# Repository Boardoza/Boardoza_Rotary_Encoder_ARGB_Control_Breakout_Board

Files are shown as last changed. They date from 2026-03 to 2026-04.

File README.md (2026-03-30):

# Boardoza Rotary Encoder EC1101S Breakout Board

The **Boardoza Rotary Encoder EC1101S Breakout Board** is a multifunctional input and visual feedback solution that combines a **mechanical rotary encoder with an integrated push button** and **addressable RGB LEDs (ARGB)** on a single compact PCB. This board converts rotational motion into digital signals while simultaneously enabling dynamic visual effects through programmable LEDs.

By integrating **14 cascaded ARGB LEDs** directly around the encoder, the board allows users to visually represent rotation, direction, speed, or system states. Each encoder movement can be interpreted by a microcontroller (such as Arduino, ESP32, or similar platforms) to control LED color, brightness, and animation patterns, making it ideal for interactive interfaces, control panels, and creative electronics projects.

## [Click here to purchase!](https://www.ozdisan.com/ureticiler/boardoza)

| Front Side | Back Side |
|:---:|:---:|
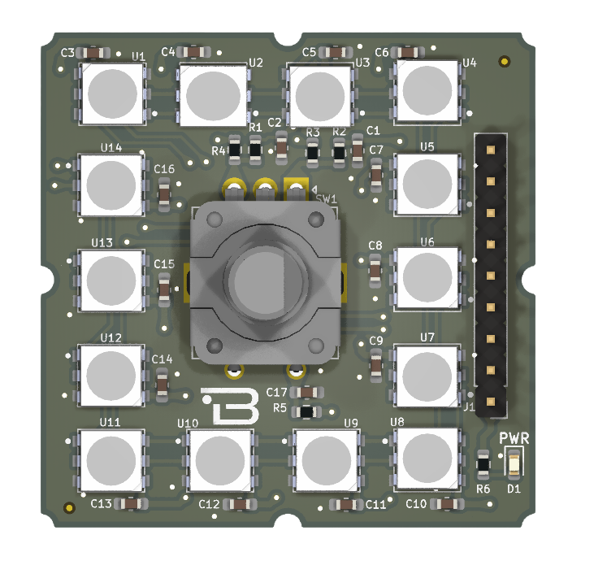
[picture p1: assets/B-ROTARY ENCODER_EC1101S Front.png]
ROTARY ENCODER EC1101S Front
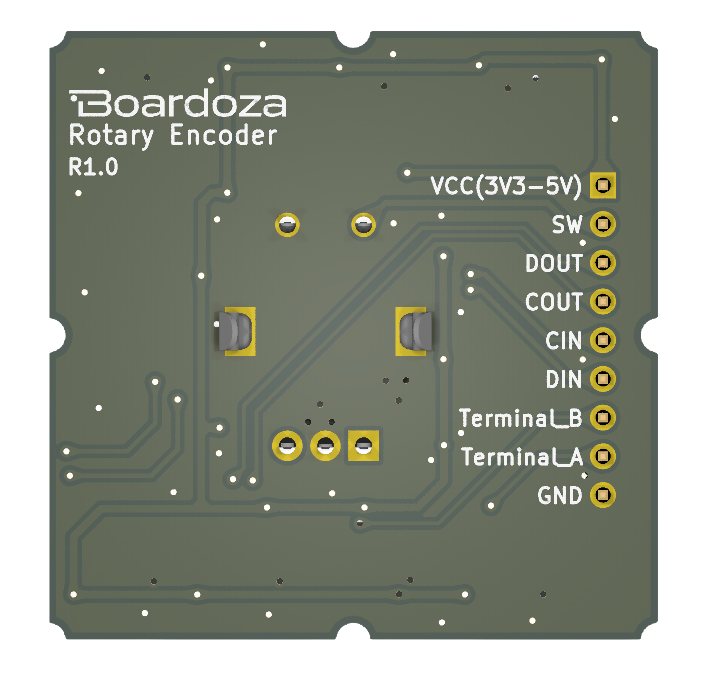
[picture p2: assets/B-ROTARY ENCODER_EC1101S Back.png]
ROTARY ENCODER EC1101S Back
|  |  |

---

## Key Features

- **Rotary Encoder with Push Button:** Mechanical rotary encoder with integrated momentary push button for menu navigation and user input.
- **Integrated Addressable RGB LEDs:** Features 14 cascaded ARGB LEDs for dynamic visual feedback and animation effects.
- **Quadrature Output Signals:** Provides A and B channel outputs for accurate direction and rotation detection.
- **Visual Motion Representation:** Encoder rotation can be visually expressed through programmable LED color, pattern, and brightness changes.
- **Wide Logic Compatibility:** Fully compatible with both 3.3 V and 5 V microcontroller systems.
- **Expandable LED Chain:** ARGB data and clock input/output pins allow cascading with additional LED boards.
- **20 Pulses per Revolution:** Provides 20 pulses per 360° rotation (per phase) for precise rotational detection.

---

## Technical Specifications  

**Model:** Rotary Encoder EC1101S  
**Manufacturer:** Boardoza  
**Encoder Type:** Mechanical rotary encoder with push button  
**LED Type:** Addressable RGB (ARGB)  
**Number of LEDs:** 14  
**LED Interface:** Serial Data (DIN/DOUT), Clock (CIN/COUT)  
**Signal Outputs:** Encoder A, Encoder B, Push Button (SW)  
**Input Voltage:** 3.3 V / 5 V  
**Logic Level:** 3.3 V / 5 V compatible  
**Operating Temperature:** -40 °C to +85 °C  
**Board Dimensions:** 40 mm × 40 mm  

---

## Board Pinout

### **( J1 ) Main Connector**

| Pin Number | Pin Name | Description |
|:---:|:---:|---|
| 1 | VCC (3V3–5V) | Power supply input |
| 2 | SW | Encoder push button output (Active Low) |
| 3 | DOUT | ARGB serial data output |
| 4 | COUT | ARGB clock output |
| 5 | CIN | ARGB clock input |
| 6 | DIN | ARGB serial data input |
| 7 | Terminal_B | Encoder B channel output |
| 8 | Terminal_A | Encoder A channel output |
| 9 | GND | Ground |

---

## Board Dimensions

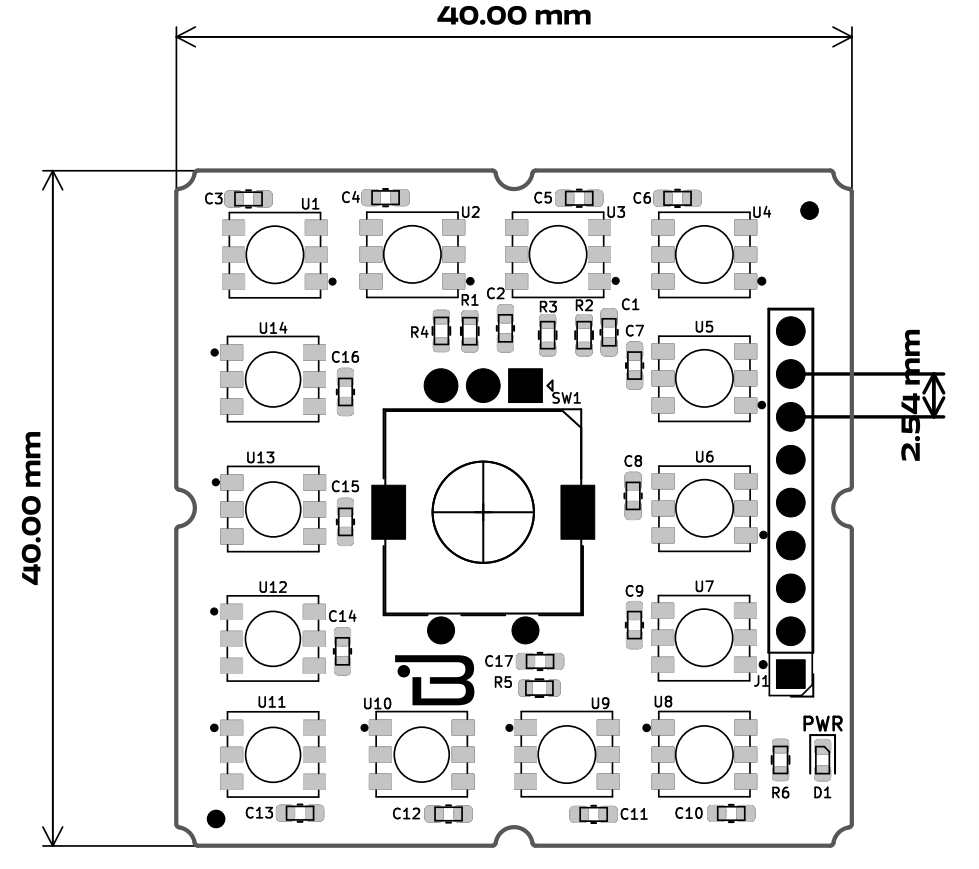
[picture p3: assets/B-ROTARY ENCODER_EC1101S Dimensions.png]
Board Dimensions


---

## Step Files

[Boardoza ROTARY ENCODER.step](./assets/B-ROTARY%20ENCODER_EC1101S%20Step.step)

---

## Datasheet

- [PLCC IC + RGB LEDs Datasheet.pdf](./assets/PLCC%20IC+RGB%20LEDs%20Datasheet.pdf)  
- [ROTARY ENCODER EC1101S Breakout Datasheet.pdf](./assets/B-ROTARY%20ENCODER_EC1101S%20Datasheet.pdf)

---

## Version History

- **V1.0.0** – Initial Release

---

## Support

- For questions or technical support, please contact **support@boardoza.com**

---

## **License**

This repository contains both hardware and software components:

### **Hardware Design**

[][cc-by-sa]

All hardware design files are licensed under [Creative Commons Attribution-ShareAlike 4.0 International License][cc-by-sa].

[cc-by-sa]: http://creativecommons.org/licenses/by-sa/4.0/
[cc-by-sa-shield]: https://img.shields.io/badge/License-CC%20BY--SA%204.0-lightgrey.svg

### **Software/Firmware**

[][bsd]

All software and firmware are licensed under [BSD 3-Clause License][bsd].

[bsd]: https://opensource.org/licenses/BSD-3-Clause
[bsd-shield]: https://img.shields.io/badge/License-BSD%203--Clause-blue.svg

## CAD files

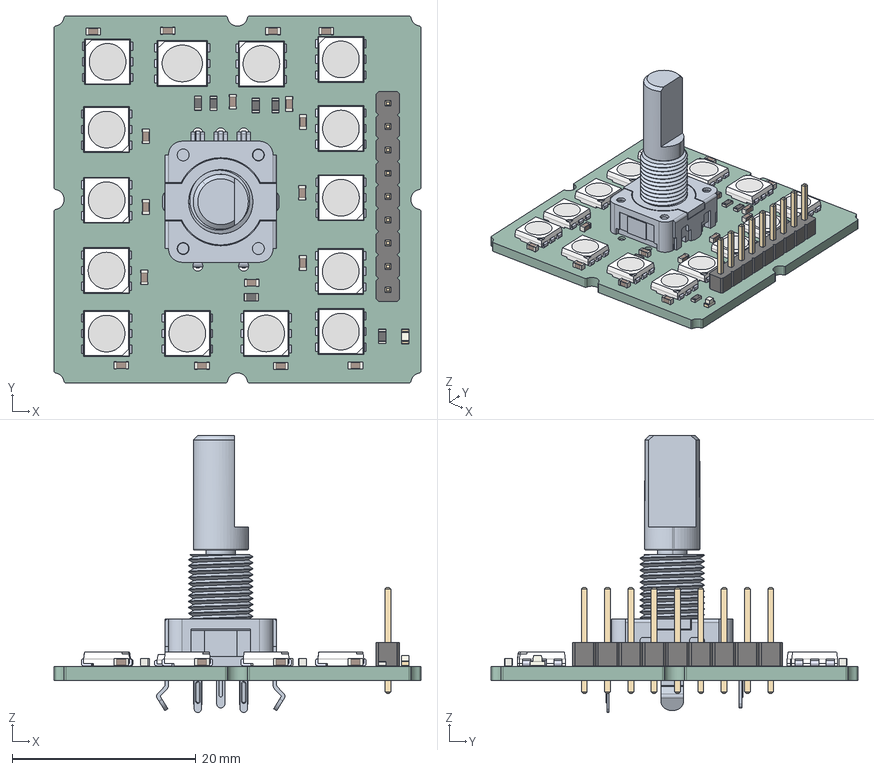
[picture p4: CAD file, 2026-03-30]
assets/B-ROTARY ENCODER_EC1101S Step.step
40.0 x 40.0 x 30.2 mm
C_0603_1608Metric x 17
IN-P55TATRGB--3DModel-STEP-56544 x 14
R_0603_1608Metric x 6
pec11r-4220f-n0012
PinHeader_1x09_P2.54mm_Vertical
LED_0603_1608Metric
B-ROTARY_ENCODER-BRK-01MBR-R01_PCB

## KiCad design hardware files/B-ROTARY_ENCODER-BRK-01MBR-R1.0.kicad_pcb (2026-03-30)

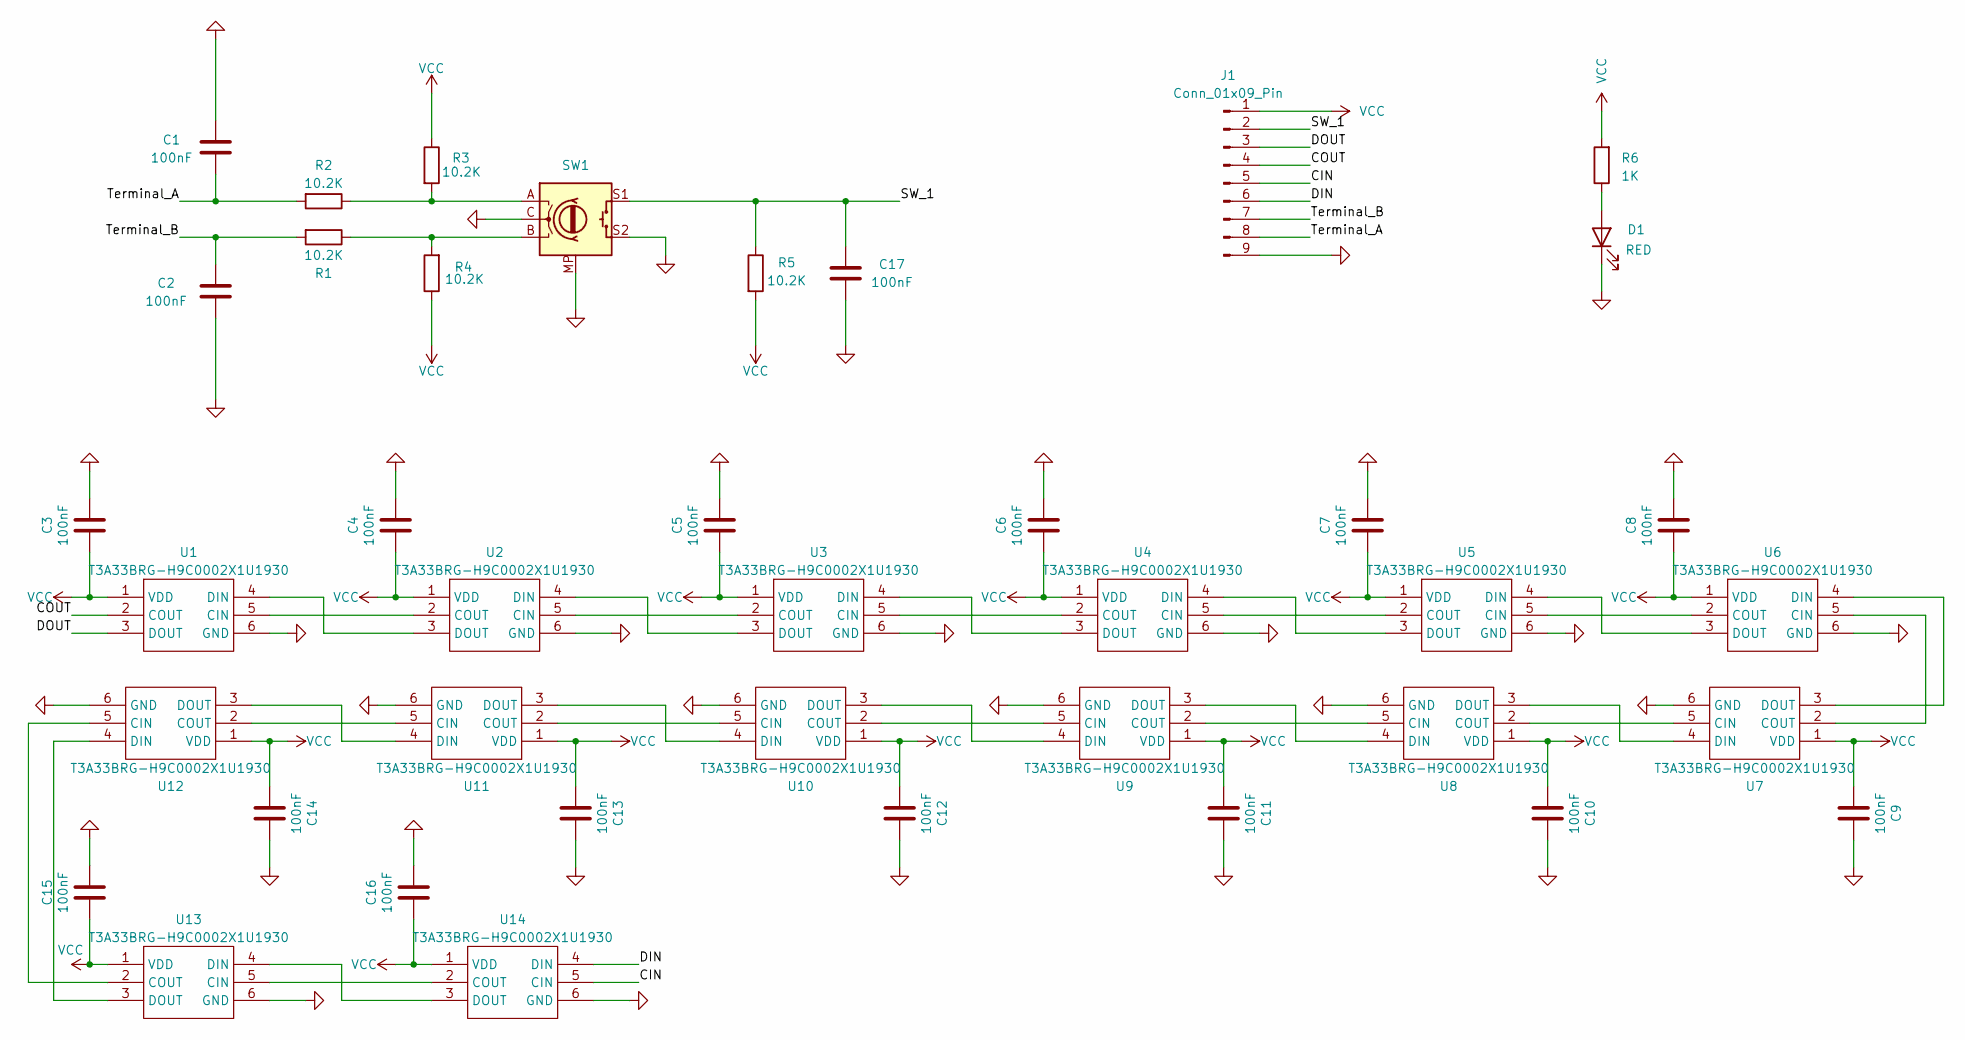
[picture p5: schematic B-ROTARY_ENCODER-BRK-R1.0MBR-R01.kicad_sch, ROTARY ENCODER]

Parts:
C1, C2, C3, C4, C5, C6, C7, C8, C9, C10, C11, C12, C13, C14, C15, C16, C17: 100nF; C_0603_1608Metric_Pad1.08x0.95mm_HandSolder; MPN CL10B104KB8NNNC
D1: RED; LED_0603_1608Metric; MPN LTST-C190KRKT
J1: Conn_01x09_Pin; PinHeader_1x09_P2.54mm_Vertical; MPN DS1021-1X9SF11-B
R1, R2, R3, R4, R5: 10.2K; R_0603_1608Metric; MPN 0603SAF1022T5E
R6: 1K; R_0603_1608Metric; MPN RC0603JR-071KL
SW1: RotaryEncoder_Switch_MP; L-KLS4-EC1123S-E-5A-F20; MPN L-KLS4-EC1123S-E-5A-F20
U1, U2, U3, U4, U5, U6, U7, U8, U9, U10, U11, U12, U13, U14: T3A33BRG-H9C0002X1U1930; ARGB_T3A33BRG-H9C0002X1U1930; MPN T3A33BRG-H9C0002X1U1930

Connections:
/CIN: J1.5, U14.5 (CIN)
/COUT: J1.4, U1.2 (COUT)
/DIN: J1.6, U14.4 (DIN)
/DOUT: J1.3, U1.3 (DOUT)
/SW_1: C17.2, J1.2, R5.1, SW1.S1
/Terminal_A: C1.1, J1.8, R2.2
/Terminal_B: C2.2, J1.7, R1.2
GND: C1.2, C2.1, C3.2, C4.2, C5.2, C6.2, C7.2, C8.2, C9.2, C10.2, C11.2, C12.2, C13.2, C14.2, C15.2, C16.2, C17.1, D1.1 (K), J1.9, SW1.C, SW1.MP, SW1.S2, U1.6 (GND), U2.6 (GND), U3.6 (GND), U4.6 (GND), U5.6 (GND), U6.6 (GND), U7.6 (GND), U8.6 (GND), U9.6 (GND), U10.6 (GND), U11.6 (GND), U12.6 (GND), U13.6 (GND), U14.6 (GND)
unnamed: D1.2 (A), R6.1
unnamed: R1.1, R4.2, SW1.B
unnamed: R2.1, R3.2, SW1.A
unnamed: U1.5 (CIN), U2.2 (COUT)
unnamed: U1.4 (DIN), U2.3 (DOUT)
unnamed: U2.5 (CIN), U3.2 (COUT)
unnamed: U2.4 (DIN), U3.3 (DOUT)
unnamed: U3.5 (CIN), U4.2 (COUT)
unnamed: U3.4 (DIN), U4.3 (DOUT)
unnamed: U4.5 (CIN), U5.2 (COUT)
unnamed: U4.4 (DIN), U5.3 (DOUT)
unnamed: U5.5 (CIN), U6.2 (COUT)
unnamed: U5.4 (DIN), U6.3 (DOUT)
unnamed: U6.5 (CIN), U7.2 (COUT)
unnamed: U6.4 (DIN), U7.3 (DOUT)
unnamed: U7.5 (CIN), U8.2 (COUT)
unnamed: U7.4 (DIN), U8.3 (DOUT)
unnamed: U8.5 (CIN), U9.2 (COUT)
unnamed: U8.4 (DIN), U9.3 (DOUT)
unnamed: U10.5 (CIN), U11.2 (COUT)
unnamed: U9.5 (CIN), U10.2 (COUT)
unnamed: U10.4 (DIN), U11.3 (DOUT)
unnamed: U9.4 (DIN), U10.3 (DOUT)
unnamed: U11.5 (CIN), U12.2 (COUT)
unnamed: U11.4 (DIN), U12.3 (DOUT)
unnamed: U12.5 (CIN), U13.2 (COUT)
unnamed: U12.4 (DIN), U13.3 (DOUT)
unnamed: U13.5 (CIN), U14.2 (COUT)
unnamed: U13.4 (DIN), U14.3 (DOUT)
VCC: C3.1, C4.1, C5.1, C6.1, C7.1, C8.1, C9.1, C10.1, C11.1, C12.1, C13.1, C14.1, C15.1, C16.1, J1.1, R3.1, R4.1, R5.2, R6.2, U1.1 (VDD), U2.1 (VDD), U3.1 (VDD), U4.1 (VDD), U5.1 (VDD), U6.1 (VDD), U7.1 (VDD), U8.1 (VDD), U9.1 (VDD), U10.1 (VDD), U11.1 (VDD), U12.1 (VDD), U13.1 (VDD), U14.1 (VDD)

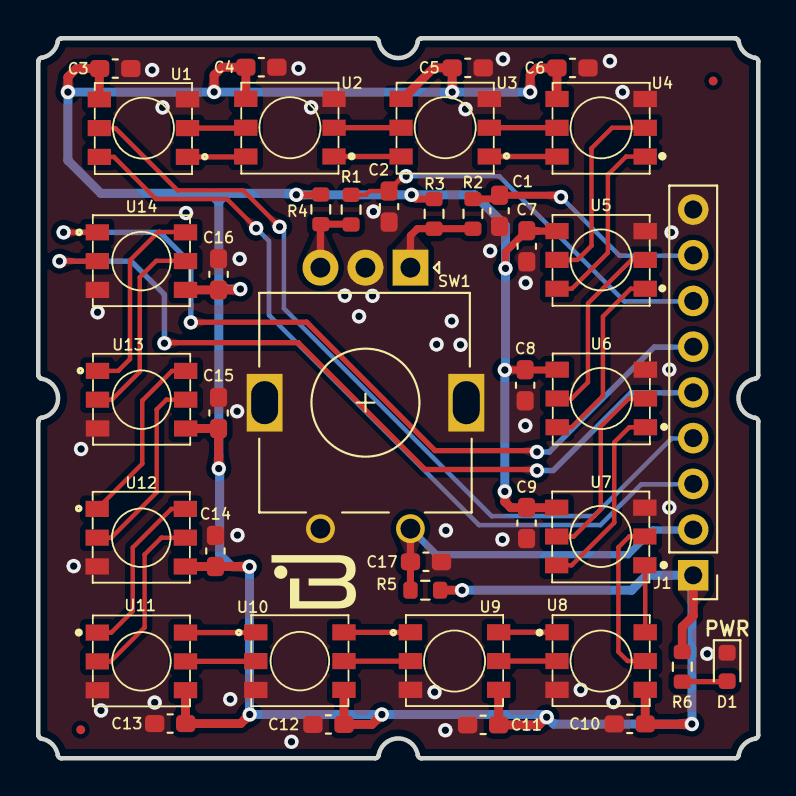
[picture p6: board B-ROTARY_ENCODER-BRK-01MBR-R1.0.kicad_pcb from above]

Board: 2 copper layers, 40.0 x 40.0 mm, 40 parts (0 on the bottom side), 38 nets.

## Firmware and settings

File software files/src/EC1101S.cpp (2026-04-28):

#include "EC1101S.h"

EC1101S* EC1101S::instance_ = nullptr;

/**
 * @brief Constructor for the EC1101S class.
 *
 * Initializes an EC1101S object by assigning the specified pins for the rotary encoder
 * and setting default values for internal variables. This constructor prepares the
 * object for use with a rotary encoder that includes A, B, and optional button pins.
 *
 * @param pinA The pin number connected to the A terminal of the rotary encoder.
 * @param pinB The pin number connected to the B terminal of the rotary encoder.
 * @param pinSW The pin number connected to the button switch of the rotary encoder (optional).
 *
 * Example usage:
 * @code
 * EC1101S encoder(33, 21, 22);  // A: Pin 33, B: Pin 21, SW: Pin 22
 * @endcode
 */
EC1101S::EC1101S(uint8_t pinA, uint8_t pinB, uint8_t pinSW) :
  _pinA(pinA),
  _pinB(pinB),
  _pinSW(pinSW),
  _prevA(0),
  _prevB(0),
  _count(0),
  _click(0),
  _CW(0),
  _debounce(0),
  _maxCount(100)
{ }

/**
 * @brief Initializes the EC1101S rotary encoder.
 *
 * This function configures the rotary encoder pins, sets up their initial states,
 * and attaches an interrupt to handle changes on the A pin. It should be called
 * before using any other functions of the EC1101S class.
 * * Example usage:
 * @code
 * encoder.begin();              // Initialize the encoder
 * @endcode
 */
void EC1101S::begin()
{
    instance_ = this;  // This pointer is sufficient if we use a single encoder

    // Pin settings
    pinMode(_pinA, INPUT_PULLUP);
    pinMode(_pinB, INPUT_PULLUP);
    pinMode(_pinSW, INPUT_PULLUP);

    // Read the previous pin values
    _prevA = digitalRead(_pinA);
    _prevB = digitalRead(_pinB);

    // Add interrupt
    attachInterrupt(digitalPinToInterrupt(_pinA), EC1101S::isrA, CHANGE);
}

/**
 * @brief Sets the maximum count value for the rotary encoder.
 *
 * This function defines the upper limit for the encoder's count value. 
 * When the count reaches this value, it will not increment further.
 *
 * @param maxVal The maximum count value to set.
 *
 * Example usage:
 * @code
 * encoder.setMaxCount(100);  // Set the maximum count to 100
 * @endcode
 */
void EC1101S::setMaxCount(uint8_t maxVal)
{
    _maxCount = maxVal;
}

/**
 * @brief Sets the current count value for the rotary encoder.
 *
 * This function allows manually setting the current count value. 
 * It can be used to reset the count or initialize it to a specific value.
 *
 * @param val The count value to set.
 *
 * Example usage:
 * @code
 * encoder.setCount(50);  // Set the current count to 50
 * @endcode
 */
void EC1101S::setCount(uint8_t val)
{
    _count = val;
}

/**
 * @brief Gets the current count value of the rotary encoder.
 *
 * This function retrieves the current count value, which is updated
 * based on the rotary encoder's movements.
 *
 * @return The current count value.
 *
 * Example usage:
 * @code
 * uint8_t count = encoder.getCount();  // Get the current count value
 * @endcode
 */
uint8_t EC1101S::getCount() const
{
    return _count;
}

/**
 * @brief Updates the rotary encoder's state and adjusts the count value.
 *
 * This function processes the rotary encoder's state changes, applies debounce logic,
 * and increments or decrements the count value based on the rotation direction.
 * It should be called regularly in the `loop` function to ensure the encoder's state
 * is up to date.
 *
 * Example usage:
 * @code
 * while (true) {
 * encoder.update();  // Update the encoder state
 * }
 * @endcode
 */
void EC1101S::update()
{
    // Decrease the debounce counter
    if (_debounce)
    {
        _debounce--;
    }

    // If a click (rotation) occurred, set the count value
    if (_click)
    {
        if (_CW)
        {
            if (_count < _maxCount)
            {
                _count++;
            }
        }
        else
        {
            if (_count > 0)
            {
                _count--;
            }
        }
        _click = 0; // Reset after processing
    }
}

/**
 * @brief Interrupt service routine (ISR) for the A pin of the rotary encoder.
 *
 * This function is triggered whenever a state change occurs on the A pin of the rotary encoder.
 * As it is declared as `static`, it uses the singleton `instance_` to call the `checkEncoder` 
 * method for processing the encoder's state. The function is designed to work with the `attachInterrupt`
 * mechanism.
 *
 * @note This function is marked with `IRAM_ATTR` to ensure it runs from IRAM, 
 * as required for interrupt handlers in some microcontrollers (e.g., ESP32).
 *
 * Example usage:
 * @code
 * attachInterrupt(digitalPinToInterrupt(33), EC1101S::isrA, CHANGE);
 * @endcode
 */
void IRAM_ATTR EC1101S::isrA()
{
    // This static function calls the class member function via instance_
    if (instance_ != nullptr)
    {
        instance_->checkEncoder();
    }
}

/**
 * @brief Processes the rotary encoder state to determine direction and update state variables.
 *
 * This function reads the current state of the rotary encoder's A and B pins and checks
 * for changes. It determines the direction of rotation (clockwise or counter-clockwise)
 * based on the pin states and updates internal variables accordingly. It is typically
 * called by the interrupt service routine `EC1101S::isrA`.
 *
 * @note This function is called internally and should not be called directly in most cases.
 *
 * Example usage (indirect):
 * @code
 * void IRAM_ATTR EC1101S::isrA()
 * {
 * if (instance_ != nullptr)
 * {
 * instance_->checkEncoder();  // Calls this function
 * }
 * }
 * @endcode
 */
void EC1101S::checkEncoder()
{   
    terminalA = digitalRead(_pinA);
    terminalB = digitalRead(_pinB);
    
    // Check the change on both A and B
    if ((_prevA != terminalA) || (_prevB != terminalB))
    {
        // If there was a change on pin A
        if (_prevA != terminalA)
        {
            // Direction calculation:
            if ((terminalB && !terminalA) ||
                (!terminalB && terminalA))
            {
                _CW = 1; // clockwise
            }
            else
            {
                _CW = 0; // counter-clockwise
            }

            _prevA = terminalA;
            _prevB = terminalB;
            _click = 1; 
        }
        else
        {
            // If there was a change on pin B
            if ((!terminalB && terminalA) ||
                (terminalB && !terminalA))
            {
                _CW = 0;
            }
            else
            {
                _CW = 1;
            }
            _prevB = terminalA;
            _prevB = terminalB;
            _click = 1;
        }
    }
}

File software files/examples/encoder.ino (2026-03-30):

#include "EC1101S.h"

#define TERMINAL_A 33
#define TERMINAL_B 21
#define SW         22

EC1101S encoder(TERMINAL_A, TERMINAL_B, SW);

void setup() {
  Serial.begin(115200);

  encoder.begin();

  // Set the maximum count value (optional)
  encoder.setMaxCount(100);
}

void loop() {
  // The update method must be called in every loop iteration
  encoder.update();

  // Read the current count value
  static uint8_t oldCount = 0;
  uint8_t currentCount = encoder.getCount();

  // Print only when the value changes
  if (currentCount != oldCount) {
    Serial.print("Count: ");
    Serial.println(currentCount);
    oldCount = currentCount;
  }

  // Check the button state
  if (!digitalRead(SW)) {
    Serial.println("Button pressed!");
    delay(200); // Simple debounce for the serial print
  }
}

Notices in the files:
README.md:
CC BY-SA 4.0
